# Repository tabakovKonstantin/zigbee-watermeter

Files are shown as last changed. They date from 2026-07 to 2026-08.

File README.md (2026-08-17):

# XIAO ESP32-C6 Zigbee Water Meter

Battery-powered Zigbee water meter firmware for the Seeed Studio XIAO ESP32-C6. It counts Hall-sensor pulses, commits every accepted pulse to NVS, reports standard and custom ZCL attributes to Zigbee2MQTT, supports Zigbee OTA, and uses a hybrid light/deep-sleep policy.

The firmware is C17 on ESP-IDF 5.4.1 with Espressif Zigbee SDK 1.6.x. It is not an Arduino or PlatformIO project.

## Reference Hardware

The table describes the exact tested assembly. Compatible substitutions require their own electrical and power validation.

| Item | Exact reference | Relevant specification | Source |
| :--- | :--- | :--- | :--- |
| MCU board | Seeed Studio XIAO ESP32-C6, ESP32-C6FH4 | 4 MB flash, 512 KB SRAM, native IEEE 802.15.4, 21 x 17.8 mm | [Seeed product guide](https://wiki.seeedstudio.com/xiao_esp32c6_getting_started/), [schematic](https://files.seeedstudio.com/wiki/SeeedStudio-XIAO-ESP32C6/XIAO-ESP32-C6_v1.0_SCH_PDF_24028.pdf) |
| Battery | Marking `YJ781139/2C` | LiPo, 3.7 V nominal, 320 mAh, 1.184 Wh | Cell marking; protection circuit and thresholds are not documented |
| Hall sensor | Texas Instruments `DRV5032FBLPG` | 5 Hz, typically 0.54 uA, omnipolar, push-pull, TO-92/LPG, 1.65-5.5 V | [TI part page](https://www.ti.com/product/DRV5032/part-details/DRV5032FBLPG), [datasheet](https://www.ti.com/lit/ds/symlink/drv5032.pdf) |
| Sensor bypass capacitor | Suntan `008WL2A104KSBB5081R` | 100 nF, 100 V, X7R, +/-10%, through-hole, 5.08 mm pitch | [Comet order code 5774](https://store.comet.bg/en/Catalogue/Product/5774/) |
| Battery divider | `2 x 200 kOhm` resistors | 1:2 divider; exact manufacturer, tolerance, and power rating are unknown | As-built assembly |
| Zigbee antenna | Quectel `YF0023AA` | Adhesive FPC, U.FL, 2.4-2.5 GHz band, 5.0 dBi listed gain, 23 x 12 mm, 100 mm cable | [Comet order code 46832](https://store.comet.bg/en/Catalogue/Product/46832/) |
| Water meter | Maddalena `SJM20.0I0M` as marked | DN20, 130 mm, R100, T50, Q3 4.0 m3/h, `P=10 L` | Unit nameplate; [Maddalena single-jet family](https://www.maddalena.it/en/mecto-sj-plus-sj-evo-water-meter-non-stop-innovation/) |

The LiPo wires are soldered directly to the XIAO `BAT+` and `BAT-` pads. The XIAO onboard charger charges the 3.7 V cell from USB-C. Verify polarity before connecting the battery. Do not connect the cell to `3V3` or `5V`.

## Wiring

```text
LiPo positive  ------------------------------------------ XIAO BAT+
LiPo negative  ------------------------------------------ XIAO BAT- / GND

XIAO BAT+ ---- 200 kOhm ----+---- XIAO A0 / D0 / GPIO0
                             |
                          200 kOhm
                             |
XIAO GND --------------------+

XIAO 3V3 ----------------------------------------------- DRV5032 VCC
XIAO GND ----------------------------------------------- DRV5032 GND
XIAO D1 / GPIO1 <--------------------------------------- DRV5032 OUT

                       100 nF
DRV5032 VCC -------------||----------------------------- DRV5032 GND
                  mount close to sensor

XIAO U.FL ------------------------------------------------ Quectel YF0023AA
```

There is no capacitor on `GPIO0/A0` in the tested battery-divider assembly. The only added capacitor is the 100 nF sensor bypass capacitor between DRV5032 VCC and GND.

The DRV5032 output is push-pull, so GPIO1 has no firmware or external pull-up. A falling edge is one 10 L pulse; a rising edge rearms the input. Holding the output low counts one pulse and then sleeps while waiting for release. An ordinary power-on/reset with the output already low does not count a pulse.

The 200 kOhm/200 kOhm divider draws about 10.5 uA at 4.2 V. GPIO0 uses ESP32-C6 eFuse curve-fitting ADC calibration and 16 averaged samples. Battery percentage is a linear trend indicator from 3300 mV (0%) to 4200 mV (100%), not a precise LiPo state-of-charge model.

## External Antenna

The production assembly uses only the external U.FL antenna. On every full application boot:

- GPIO3 is driven low to enable control of the XIAO RF switch.
- GPIO14 is driven high to select the external U.FL path.
- Both pins are floated immediately before deep sleep to avoid holding the RF switch active.

A missing, damaged, or poorly placed antenna can cause repeated joins or report retries and dominate energy consumption. Test the link with the final enclosure and installation position.

## Enclosure And Print Files

The enclosure models are stored separately from the firmware:

- `enclosure/cad/watermeter_enclosure_box.step` is the STEP exchange model for CAD changes.
- `enclosure/print/watermeter_enclosure_box.stl` is the main enclosure box for 3D printing.
- `enclosure/print/watermeter_enclosure_lid.stl` is the removable enclosure lid.
- `enclosure/print/watermeter_enclosure_sensor_probe.stl` is the probe that holds the Hall sensor in the
  water meter pulse opening.

The repository does not prescribe printer, material, orientation, support, or slicer settings. Verify the fit of all
parts, especially the sensor probe, before final installation.

## Firmware Architecture

| Module | Responsibility |
| :--- | :--- |
| `main/watermeter.c` | Application bootstrap and ESP-IDF platform initialization |
| `main/meter_state.c` | NVS-backed pulse count and scale settings |
| `main/sensor.c` | GPIO ISR, debounce, pulse task, and per-pulse persistence |
| `main/battery.c` | ADC lifecycle and Battery cluster updates |
| `main/battery_math.c` | Pure ADC/divider/percentage calculations |
| `main/meter_math.c` | Pure summation and ZCL integer conversion helpers |
| `main/power_schedule.c` | Pure report and retry scheduling calculations |
| `main/sleep_control.c` | Zigbee sleep, light-sleep sessions, deep-sleep wake/release state |
| `main/xiao_board.c` | XIAO external antenna control |
| `main/zigbee_clusters.c` | Per-cluster builders and endpoint construction |
| `main/zigbee_app.c` | Zigbee lifecycle, commissioning, reporting, and callbacks |
| `main/ota.c` | OTA validation, writing, finalization, and deferred restart |

## Stable Zigbee Contract

Endpoint `1` exposes standard Basic, Identify, Metering, Power Configuration, Poll Control, and OTA client clusters. The externally visible meter contract is:

| Value | Contract |
| :--- | :--- |
| `CurrentSummationDelivered` | Raw persistent pulse count |
| Metering `Multiplier` / `Divisor` | Read-only mirrors of the configured scale |
| Custom `0xFC00` | Scaled summation |
| Custom `0xFC01` | Writable positive scale multiplier |
| Custom `0xFC02` | Writable positive scale divisor |
| Battery voltage / percentage | Standard Power Configuration attributes |
| Default scale | `10 / 1`, so one pulse reports 10 L |

Every accepted pulse is committed to NVS immediately. This intentionally prioritizes water accounting across sudden power loss over flash wear.

## Operations Harness

The dependency-free Python harness is the preferred entry point. It discovers ESP-IDF v5.4.1 and serial ports, reads partition addresses from `partitions.csv`, isolates build profiles, and enforces destructive-operation confirmations.

```bash
python3 tools/watermeter_harness.py doctor
python3 tools/watermeter_harness.py ports
python3 tools/watermeter_harness.py test
python3 tools/watermeter_harness.py build
python3 tools/watermeter_harness.py check-size
```

Run `python3 tools/watermeter_harness.py --help` for all commands. Detailed AI/operator workflows live in:

- `.agents/skills/watermeter-firmware/SKILL.md`
- `.agents/skills/watermeter-hardware-test/SKILL.md`
- `.agents/skills/watermeter-z2m/SKILL.md`

## Manual Build

The equivalent production build is:

```bash
. $HOME/.espressif/tools/activate_idf_v5.4.1.sh
idf.py set-target esp32c6
idf.py build
```

`sdkconfig.defaults` is the production source of truth. Generated `sdkconfig` files are not defaults. The build is valid only when `build/watermeter.bin` is strictly smaller than the `0x1E0000` OTA slot parsed from `partitions.csv`.

Run the pure host tests without an ESP32:

```bash
python3 -m unittest discover -s tests/python -p 'test_*.py'
cmake -S tests -B build-host-tests
cmake --build build-host-tests
ctest --test-dir build-host-tests --output-on-failure
```

## Flash And Logs

Normal flashing builds first and preserves pulse NVS and Zigbee pairing:

```bash
python3 tools/watermeter_harness.py flash --profile production
python3 tools/watermeter_harness.py monitor --profile production
```

The harness auto-selects the port only when exactly one candidate exists. Use `--port` when several boards are connected. XIAO native USB may remain in ROM download mode after flashing; press RESET once without holding BOOT. A disappearing USB port after normal startup is expected when production firmware enters deep sleep.

Do not erase flash to fix a monitor reconnect or ROM download-mode condition.

### Diagnostic Profile

Diagnostic mode has an independent `sdkconfig.diagnostic` and `build-diagnostic`:

```bash
python3 tools/watermeter_harness.py build-diagnostic
python3 tools/watermeter_harness.py flash --profile diagnostic
python3 tools/watermeter_harness.py monitor --profile diagnostic
```

It enables INFO logs and USB Serial/JTAG while preserving NVS and Zigbee storage. It changes awake time and current, so never use it for battery measurements. Restore production firmware after diagnosis.

### Erase Policy

Ordinary flash never erases state. Recovery commands require exact confirmations:

```bash
# Preserves pulse NVS but clears pairing; permit join is required afterward.
python3 tools/watermeter_harness.py erase-zigbee --confirm 'ERASE ZIGBEE'

# Destroys firmware, pulse count, OTA state, and pairing.
python3 tools/watermeter_harness.py erase-all --confirm 'ERASE ALL'
```

The Zigbee partition offset is never copied into documentation or scripts; it is parsed from `partitions.csv` at runtime.

## Sleep Policy

Production uses a hybrid policy. The CPU and Zigbee stack use automatic light sleep while an application session is open, then the device enters deep sleep between sessions.

1. An ordinary power-on/reset does not count GPIO1 already being low.
2. Idle deep sleep waits for GPIO1 or the retained report timer.
3. A falling GPIO wake counts once and commits immediately to NVS.
4. Both mandatory Metering reports must succeed within a 10-second delivery window.
5. If GPIO1 is high, a 30-second activity window reuses the live Zigbee session; every new pulse restarts it.
6. If GPIO1 remains low, the device deep-sleeps waiting for GPIO1 high instead of blocking a task.
7. The release wake rearms GPIO1 low and returns directly to deep sleep without counting or starting Zigbee.
8. A scheduled wake reports the meter and returns to deep sleep without the pulse grace window.

Failed mandatory reports retry after 5, 15, 30, and then 55 minutes. A successful delivery resets the backoff. Factory-new commissioning gets one 2-minute window; later attempts are limited to 10 seconds and use the same backoff. Battery reporting is attempted on first ordinary boot and every 6 hours without blocking meter delivery. OTA temporarily blocks deep sleep and uses a faster parent poll.

### Production Defaults

| Setting | Default |
| :--- | ---: |
| Sleep mode | Hybrid deep/light |
| Active HP CPU | Fixed 160 MHz |
| Sensor debounce | 1 s |
| Normal meter timer | 55 min |
| Battery report timer | 6 h |
| Pulse activity grace | 30 s |
| Mandatory delivery window | 10 s |
| Optional report flush | 500 ms |
| Parent poll during delivery | 1 s |
| Parent poll during OTA | 500 ms |
| Zigbee keep-alive | 55 min |
| End-device aging timeout | 128 min |
| IEEE 802.15.4 TX power | 20 dBm |
| Retry delays | 5/15/30/55 min |

All tunable values are defined in `main/Kconfig.projbuild` and selected in `sdkconfig.defaults`.

## Zigbee2MQTT Converter

The canonical external converter is:

```text
external_converters/zigbeehive-watermeter.mjs
```

The matching device icon is:

```text
external_converters/device_icons/zigbeehive-watermeter.png
```

Zigbee2MQTT 2.11 and newer requires `advanced.enable_external_js: true`. Install the standalone file under the Zigbee2MQTT data directory's `external_converters/` folder. This repository does not own unrelated Tuya or light-sensor converters.

Install the icon under `<zigbee2mqtt-data>/device_icons/` and select it for the device:

```yaml
devices:
  '0xb43a45fffe8a73c4':
    icon: device_icons/zigbeehive-watermeter.png
```

Audit the configured homelab without modifying it:

```bash
python3 tools/watermeter_harness.py z2m-audit
```

Deployment requires the state-bound token printed by a separately reviewed audit plus its typed confirmation. Rollback requires a separate typed confirmation. See `.agents/skills/watermeter-z2m/SKILL.md` before changing the remote host.

## Zigbee OTA

| Header field | Value |
| :--- | :--- |
| Magic | `0x0BEEF11E` |
| Manufacturer code | `0x131B` |
| Image type | `0x0001` |
| File version | Explicit monotonic `OTA_FILE_VERSION` |

Create a local image with an explicit version:

```bash
python3 tools/watermeter_harness.py ota-build --file-version 42
```

GitHub Actions uses `github.run_number`, verifies the binary size, creates the Zigbee `.ota` and `index.json`, and publishes them through GitHub Pages from `main`. Zigbee2MQTT must use the generated index; never offer raw `watermeter.bin` as a Zigbee OTA image.

OTA slots have rollback enabled. A successful boot marks the image valid early in `app_main`. OTA completion schedules a deferred restart instead of restarting inside the Zigbee callback.

## Power Validation

The Hall sensor and divider together account for roughly 11 uA typical before XIAO board losses. A 320 mAh cell discharging in two days therefore indicates substantial additional board current, prolonged awake time, RF retries, charging-path effects, a damaged cell, or another hardware fault; firmware settings alone cannot identify the cause.

Validate in the production profile with USB disconnected:

1. Confirm idle deep-sleep current with GPIO1 high and the coordinator available.
2. Hold the Hall output low and verify one count, no watchdog, and return to deep-sleep current while waiting for release.
3. Turn off the coordinator and verify bounded 10-second attempts followed by configured retry sleeps.
4. Generate pulses less than 30 seconds apart and compare one reused session with repeated cold boots.
5. Test the external antenna in its final placement.
6. Record battery voltage, real pulse activity, outages, and resets over several days.

A multimeter voltage trend can expose severe drain but cannot separate sleep current, radio bursts, regulator loss, and LiPo discharge behavior. Use an in-series current instrument capable of resolving both microamp sleep and radio peaks for a defensible energy budget.

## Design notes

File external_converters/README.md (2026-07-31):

# Zigbee2MQTT External Converter

`zigbeehive-watermeter.mjs` is the canonical and only WaterMeter converter maintained by this repository. It is a standalone ES module for Zigbee2MQTT 2.x.

Install it as:

```text
<zigbee2mqtt-data>/external_converters/zigbeehive-watermeter.mjs
```

Install the matching device icon as:

```text
<zigbee2mqtt-data>/device_icons/zigbeehive-watermeter.png
```

Then reference it from the device entry in `configuration.yaml`:

```yaml
devices:
  '0xb43a45fffe8a73c4':
    icon: device_icons/zigbeehive-watermeter.png
```

Zigbee2MQTT 2.11 and newer requires:

```yaml
advanced:
  enable_external_js: true
```

Audit the configured homelab before any deployment:

```bash
python3 tools/watermeter_harness.py z2m-audit
```

The audit is read-only. Deployment requires a clean, reviewed audit, its state-bound approval token, and the exact `DEPLOY Z2M` confirmation. See `.agents/skills/watermeter-z2m/SKILL.md` for legacy-bundle migration, complete-set backup, health checks, and rollback.

The converter exposes:

```text
pulse_count        read-only raw CurrentSummationDelivered pulses
scaled_summation   read-only pulse_count * scale_multiplier / scale_divisor
water_consumed     read-only liters for Home Assistant Energy
scale_multiplier   writable positive integer stored in device NVS
scale_divisor      writable positive integer stored in device NVS
multiplier         read-only standard Metering mirror
divisor            read-only standard Metering mirror
battery
voltage
```

The default scale is `10 / 1`, so one pulse is 10 L.

Unrelated Tuya, thermostat, or light-sensor converters belong to the Zigbee2MQTT installation that uses them. Do not add them to this firmware repository or combine them with the canonical WaterMeter converter.

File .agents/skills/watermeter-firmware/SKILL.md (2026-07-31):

---
name: watermeter-firmware
description: Build, test, flash, monitor, diagnose, and prepare USB or Zigbee OTA updates for the zigbee-watermeter ESP-IDF firmware. Use for firmware operations, serial-port discovery, production or diagnostic profiles, partition erasure, OTA image creation, binary-size checks, or ESP32-C6 troubleshooting in this repository.
---

# Watermeter Firmware

Use `tools/watermeter_harness.py` from the repository root. Treat `sdkconfig.defaults`,
`sdkconfig.diagnostic.defaults`, and `partitions.csv` as the configuration sources of truth.

## Preserve Invariants

- Use ESP-IDF v5.4.1 and target `esp32c6`.
- Keep every pulse committed to NVS immediately.
- Preserve Zigbee endpoint 1, Metering and Battery attributes, custom attributes `0xFC00`-`0xFC02`, and report formats.
- Preserve OTA magic `0x0BEEF11E`, manufacturer `0x131B`, image type `0x0001`, and dual-slot compatibility.
- Require `watermeter.bin` to be strictly smaller than the OTA slot parsed from `partitions.csv`.
- Never hardcode a serial port or partition offset. Discover the port and parse the table.
- Never erase NVS or Zigbee storage as part of an ordinary build, flash, diagnostic, or update.

## Choose The Operation

Run the environment check first on a new machine or after an ESP-IDF change:

```bash
python3 tools/watermeter_harness.py doctor
python3 tools/watermeter_harness.py ports
```

Run local tests and a production build after firmware or tooling changes:

```bash
python3 tools/watermeter_harness.py test
python3 tools/watermeter_harness.py build
python3 tools/watermeter_harness.py check-size
```

Use `--clean` only when configuration or generated build state is suspect. It removes only the selected build directory.

## Flash Safely

Build and flash production firmware without erasing state:

```bash
python3 tools/watermeter_harness.py flash --profile production
```

Pass `--port` only when more than one candidate is connected. After native USB flashing, the XIAO may remain in ROM download mode. Press RESET once without holding BOOT. Do not erase the board to fix this condition.

Monitor with the ELF matching the flashed profile:

```bash
python3 tools/watermeter_harness.py monitor --profile production
```

When an agent starts the monitor, allocate a TTY. Expect the USB port to disappear during deep sleep.

## Use Diagnostic Mode

Keep diagnostic output isolated from production artifacts:

```bash
python3 tools/watermeter_harness.py build-diagnostic
python3 tools/watermeter_harness.py flash --profile diagnostic
python3 tools/watermeter_harness.py monitor --profile diagnostic
```

Diagnostic mode enables INFO logging and USB Serial/JTAG. It preserves NVS and Zigbee pairing but changes awake time and board current. Never use it for battery-life measurements. Restore production firmware after diagnosis with `flash --profile production`.

## Erase Only With Explicit Approval

Use `erase-zigbee` only to recover corrupted pairing state. It reads the current `zb_storage` offset and size from `partitions.csv`, preserves pulse NVS, and requires re-pairing:

```bash
python3 tools/watermeter_harness.py erase-zigbee --confirm 'ERASE ZIGBEE'
```

Use `erase-all` only after the user explicitly accepts losing firmware, pulse count, OTA state, and Zigbee pairing:

```bash
python3 tools/watermeter_harness.py erase-all --confirm 'ERASE ALL'
```

Never infer either confirmation from a general request to flash, clean, repair, or retry.

## Prepare OTA

Require a user-selected monotonically increasing file version:

```bash
python3 tools/watermeter_harness.py ota-build --file-version 42
```

The command builds production firmware, checks its slot size, and writes the `.ota` image and index under `build/ota`. It does not push Git or publish a release. CI uses `github.run_number` and publishes from `main` through GitHub Pages.

## Finish A Change

Run Python/C tests, the production build, and the diagnostic build. Report both binary sizes and any test that could not run. Do not claim a hardware, Zigbee delivery, deep-sleep current, or OTA result from compilation alone.

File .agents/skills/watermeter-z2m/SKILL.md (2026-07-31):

---
name: watermeter-z2m
description: Audit, migrate, deploy, verify, and roll back the ZigbeeHive watermeter external converter on the homelab Zigbee2MQTT installation. Use for converter drift, Zigbee2MQTT support, remote configuration, external converter migration, service restart, health checks, or rollback involving homelab.lan.
---

# Watermeter Zigbee2MQTT

Use the canonical local converter at `external_converters/zigbeehive-watermeter.mjs`. The default remote installation is:

```text
SSH host:     homelab.lan
Data:         /mnt/projects/smart_home/zigbee2mqtt-data
Compose file: /mnt/projects/smart_home/compose.yml
Service:      zigbee2mqtt
Container:    zigbee2mqtt
```

The canonical local device icon is `external_converters/device_icons/zigbeehive-watermeter.png`. Install it as `device_icons/zigbeehive-watermeter.png` under the Zigbee2MQTT data directory and reference that relative path from the device entry in `configuration.yaml`.

Use SSH configuration or an SSH agent. Never place credentials or private keys in the repository.

## Audit First

Always begin with the read-only operation:

```bash
python3 tools/watermeter_harness.py z2m-audit
```

The audit checks the compose service, `advanced.enable_external_js`, converter syntax inside the running Zigbee2MQTT container, the canonical file diff, and duplicate legacy WaterMeter definitions. It may display a deployment diff but must not write or restart anything.

## Handle The One-Time Legacy Split

The existing homelab may contain one CommonJS aggregate with unrelated Tuya/TS0222 converters and a copied WaterMeter definition. This repository must not own those unrelated definitions.

If audit reports a legacy conflict:

1. Read and preserve the complete remote aggregate.
2. Prepare a timestamped backup under `/mnt/projects/smart_home/zigbee2mqtt-data/.watermeter-backups`.
3. Split only the unrelated definitions into a remote-only converter file. Preserve their imports, fingerprints, exposes, datapoints, and exports exactly.
4. Remove the WaterMeter definition from the legacy file and stage the canonical `.mjs` as a separate file.
5. Move the old aggregate outside the auto-loaded `.js`/`.mjs` paths or give the backup a non-JavaScript suffix.
6. Validate syntax in the Zigbee2MQTT container and show the exact remote diff.
7. Ask for explicit approval before writing files or restarting the service.

Do not automate this split with substring deletion when the remote file shape is uncertain. Never alter unrelated converter behavior to make the migration cleaner.

## Deploy The Canonical Converter

Deploy only after audit is clean and the user explicitly approves the shown diff and restart. Pass the token printed by that separately reviewed audit so deployment is bound to the same local and remote converter state:

```bash
python3 tools/watermeter_harness.py z2m-deploy \
    --approved-audit <token-from-z2m-audit> \
    --confirm 'DEPLOY Z2M'
```

The command reruns the audit and refuses a stale or missing token. It then backs up the current WaterMeter target, uploads to a temporary `.mjs`, checks syntax inside the container, atomically replaces the target, restarts only `zigbee2mqtt`, and prints status and recent logs. It refuses deployment while another file still defines WaterMeter.

Do not change `configuration.yaml`, other services, devices, or unrelated converters as a side effect. If `advanced.enable_external_js` is disabled, prepare and show that configuration change separately and request approval.

## Verify

After restart, require all of the following:

- the `zigbee2mqtt` service is running;
- no external-converter syntax/load error appears in recent logs;
- model `ZigbeeHive-WaterMeter` is supported;
- existing unrelated devices remain supported;
- `pulse_count`, `scaled_summation`, `water_consumed`, battery, and voltage remain available;
- writable scale values remain positive and preserve their previous values.
- the configured device icon path exists and remains scoped to the WaterMeter device.

Do not generate test pulses remotely. Use the hardware-test skill when an end-to-end pulse is required.

## Roll Back

Never roll back silently. Show the retained backup timestamp and request a separate confirmation:

```bash
python3 tools/watermeter_harness.py z2m-rollback \
    --backup 20260731T153000Z \
    --confirm 'ROLLBACK Z2M'
```

The generic rollback command restores only a standalone canonical-converter deployment. It must refuse a one-time legacy-split backup marked by `MIGRATION.txt`; restoring that backup requires the complete configuration and converter set described in the marker and a separately reviewed command.

Restart only Zigbee2MQTT and repeat the health checks. Never delete old backups automatically.

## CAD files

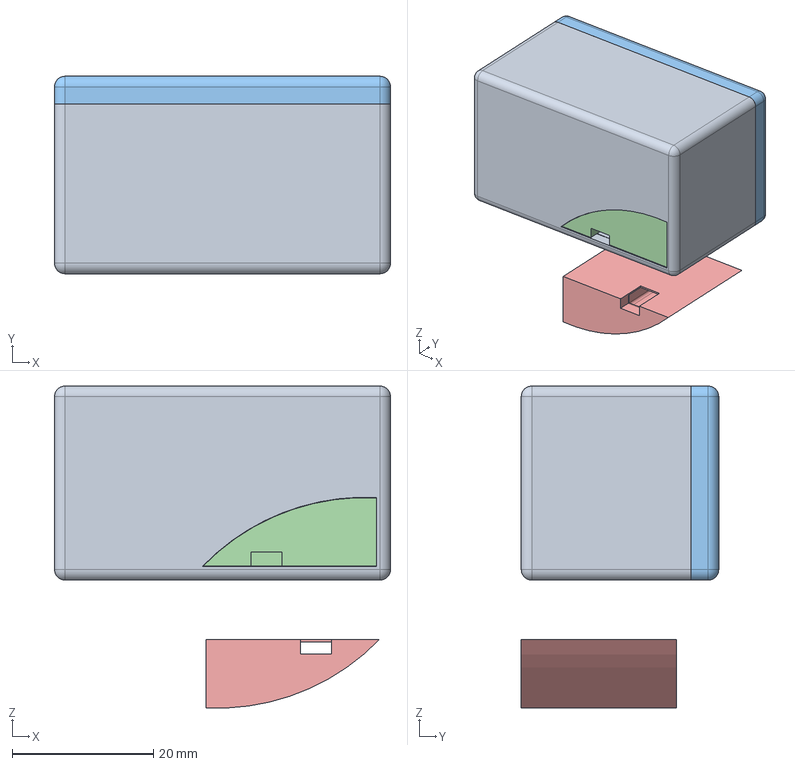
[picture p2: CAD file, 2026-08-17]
enclosure/cad/watermeter_enclosure_box.step
47.6 x 28.0 x 45.6 mm

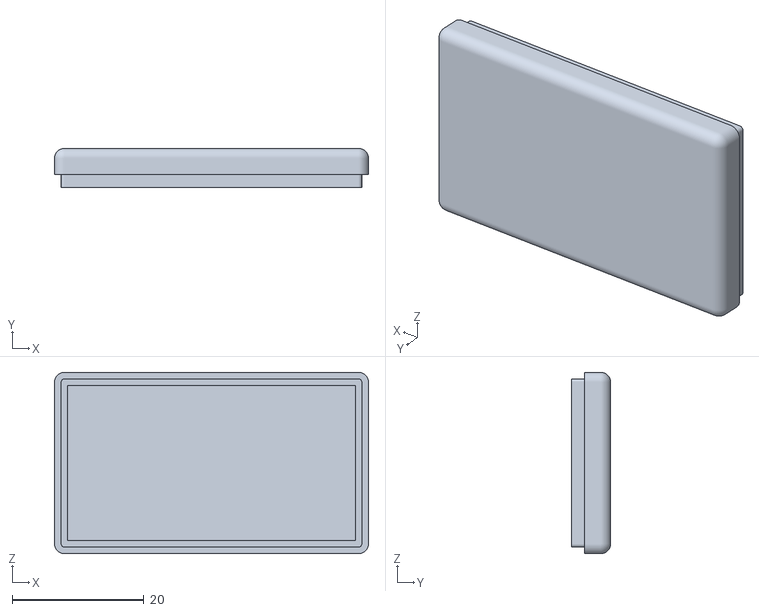
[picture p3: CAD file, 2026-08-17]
enclosure/print/watermeter_enclosure_lid.stl
47.6 x 5.95 x 27.5

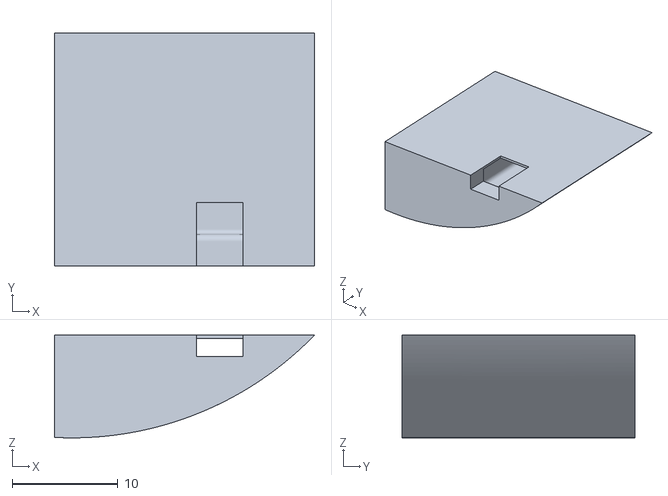
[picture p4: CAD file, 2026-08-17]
enclosure/print/watermeter_enclosure_sensor_probe.stl
24.5 x 22.0 x 9.70

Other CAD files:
enclosure/print/watermeter_enclosure_box.stl

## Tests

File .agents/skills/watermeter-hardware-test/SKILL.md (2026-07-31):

---
name: watermeter-hardware-test
description: Guide a human through safe functional and battery testing of the XIAO ESP32-C6 Zigbee water meter. Use when validating Hall pulses, stuck-low handling, phantom-pulse prevention, watchdog behavior, deep-sleep wake/release behavior, Zigbee2MQTT delivery, production restoration, or battery drain on the physical device.
---

# Watermeter Hardware Test

Run hardware validation as a human-in-the-loop procedure. Ask for one physical action at a time and wait for the result. Never pretend that a GPIO, magnet, reset button, USB cable, Zigbee coordinator, or meter was manipulated automatically.

## Protect Meter Data

- Read the current `pulse_count` from logs or Zigbee2MQTT before generating a test pulse.
- Warn that every accepted magnet pulse permanently adds one count, equal to 10 L with the production scale.
- Require explicit approval before test pulses.
- Never erase, decrement, rewrite, or compensate the NVS counter after a test.
- Record the expected and observed counter delta.

## Phase 1: Functional Diagnostic Test

Use USB power and the diagnostic profile. This phase checks behavior, not energy consumption.

1. Run `python3 tools/watermeter_harness.py doctor` and `ports`.
2. Flash with `python3 tools/watermeter_harness.py flash --profile diagnostic`. Do not erase flash.
3. Ask the user to press RESET once without BOOT if the board remains in ROM download mode.
4. Start `monitor --profile diagnostic` with a TTY and capture the baseline pulse count, boot cause, network state, and absence of NVS errors.
5. Confirm in Zigbee2MQTT that the device is recognized as `ZigbeeHive-WaterMeter` before pulse tests.

### Single Pulse

1. Confirm the Hall output is released/high.
2. Ask the user to apply the magnet once and then remove it.
3. Verify exactly one `Pulse counted` entry and a counter delta of one.
4. Reject repeated counts, queue floods, watchdog messages, or NVS errors.
5. Allow delivery on the current or a later scheduled wake; do not require an unnecessary retry loop.

### Stuck-Low And Release

1. Confirm the user accepts one additional permanent test pulse.
2. Ask the user to apply and hold the magnet for at least 15 seconds.
3. Verify one pulse only, no task-watchdog trigger, and no repeated count while the output remains low.
4. Expect deep sleep to arm a high-level wake while waiting for release; the USB port may disappear.
5. Ask the user to remove the magnet.
6. Verify the release wake rearms the low-level wake without incrementing the counter or starting a full Zigbee session.
7. Apply one later normal pulse to prove the input was rearmed; expect one additional count only.

### Reset And Phantom Pulse

1. With the Hall output released/high, reset and verify no count.
2. Hold the magnet before an ordinary RESET and keep it held through boot.
3. Verify an ordinary power-on/reset with GPIO1 already low does not count a pulse.
4. Remove the magnet and verify release does not count.
5. Stop immediately on any phantom increment or watchdog output and retain the complete log.

### Zigbee2MQTT Delivery

Verify that `pulse_count`, `scaled_summation`, and `water_consumed` converge to the expected values in Zigbee2MQTT. A mandatory delivery attempt may stop after 10 seconds and retry on a later wake. Treat eventual correct delivery without data loss as success; do not keep the device awake merely to force an immediate UI update.

## Restore Production

After functional testing:

```bash
python3 tools/watermeter_harness.py flash --profile production
```

Press RESET once without BOOT if needed. Confirm production boot, then disconnect USB. Do not leave diagnostic firmware installed for power testing.

## Phase 2: Battery Test

- Use the production profile and the final external U.FL antenna and enclosure placement.
- Power only from the 3.7 V LiPo through `BAT+`/`BAT-`; disconnect USB.
- Keep the Zigbee coordinator and parent in their normal production locations.
- Record battery voltage, timestamps, real water activity, coordinator outages, and resets over several days.
- A multimeter voltage trend can expose severe drain but cannot separate deep-sleep current, regulator loss, radio retries, or LiPo discharge-curve effects.
- For a defensible energy budget, measure current in series with the battery using equipment that resolves sleep current and radio bursts.

Do not promise a battery lifetime from voltage snapshots alone. Report observed conditions and uncertainty.

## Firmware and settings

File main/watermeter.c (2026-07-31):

#include "esp_app_desc.h"
#include "esp_log.h"
#include "esp_sleep.h"
#include "esp_zigbee_core.h"
#include "nvs_flash.h"

#include "battery.h"
#include "meter_state.h"
#include "ota.h"
#include "sensor.h"
#include "sleep_control.h"
#include "xiao_board.h"
#include "zigbee_app.h"

#define SENSOR_PIN CONFIG_WATERMETER_SENSOR_GPIO

static const char *TAG = "WATERMETER";

void app_main(void)
{
    esp_zb_platform_config_t config = {
        .radio_config = { .radio_mode = ZB_RADIO_MODE_NATIVE },
        .host_config = { .host_connection_mode = ZB_HOST_CONNECTION_MODE_NONE },
    };

    sleep_control_handle_early_wakeup();

    ESP_ERROR_CHECK(nvs_flash_init());
    ESP_LOGI(TAG, "app_main: nvs ok");
    esp_sleep_wakeup_cause_t boot_wakeup_cause = esp_sleep_get_wakeup_cause();
    ESP_LOGI(TAG, "app_main: boot wake cause=%s (%d)",
             sleep_control_wakeup_cause_name(boot_wakeup_cause), boot_wakeup_cause);

    ota_set_activity_callback(zigbee_app_set_ota_active);
    ESP_ERROR_CHECK(ota_mark_running_app_valid());
    ESP_LOGI(TAG, "app_main: firmware=%s ota_file_version=%d", esp_app_get_description()->version,
             WATERMETER_OTA_FILE_VERSION);

    ESP_ERROR_CHECK(meter_state_load());
    ESP_LOGI(TAG, "app_main: meter state ok");

    esp_err_t battery_err = battery_init();
    if (battery_err == ESP_OK) {
        ESP_LOGI(TAG, "app_main: calibrated battery adc ok on ADC1 channel 0");
    } else {
        ESP_LOGW(TAG, "app_main: battery adc unavailable: %s", esp_err_to_name(battery_err));
    }

    ESP_ERROR_CHECK(sleep_control_init_power_management());
    ESP_LOGI(TAG, "app_main: power management fixed at %d MHz", CONFIG_WATERMETER_PM_MAX_FREQ_MHZ);

    ESP_ERROR_CHECK(xiao_board_enable_external_antenna());
    ESP_ERROR_CHECK(esp_zb_platform_config(&config));
    ESP_LOGI(TAG, "app_main: zigbee platform config ok");

    const sensor_callbacks_t sensor_callbacks = {
        .is_zigbee_joined = zigbee_app_is_joined,
        .report_pulse = zigbee_app_report_sensor_pulse,
    };
    ESP_ERROR_CHECK(sensor_start(&sensor_callbacks));
    ESP_LOGI(TAG, "app_main: sensor task created");

    ESP_ERROR_CHECK(zigbee_app_start());
    ESP_LOGI(TAG, "app_main: zigbee task created");

    ESP_LOGI(TAG, "Sleep mode=%s sensor GPIO=%d", sleep_control_mode_name(), SENSOR_PIN);
}

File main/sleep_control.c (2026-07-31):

#include "sleep_control.h"

#include <inttypes.h>

#include "driver/gpio.h"
#include "esp_attr.h"
#include "esp_log.h"
#include "esp_pm.h"
#include "esp_zigbee_cluster.h"
#include "esp_zigbee_core.h"
#include "platform/esp_zigbee_platform.h"
#include "soc/esp32c6/rtc.h"

#include "ota.h"
#include "xiao_board.h"

#define SENSOR_PIN ((gpio_num_t)CONFIG_WATERMETER_SENSOR_GPIO)
#define ZIGBEE_SLEEP_THRESHOLD_MS 1000
#define ZIGBEE_AWAKE_AFTER_PULSE_MS 3000
#define SENSOR_WAKE_STATE_MAGIC 0x574D5357U
#define MIN_DEEP_SLEEP_MS 100

#if CONFIG_WATERMETER_SLEEP_MODE_DEEP && !GPIO_IS_DEEP_SLEEP_WAKEUP_VALID_GPIO(CONFIG_WATERMETER_SENSOR_GPIO)
#error "WATERMETER_SENSOR_GPIO must be a valid deep sleep wake GPIO in deep sleep mode"
#endif

static const char *TAG = "SLEEP_CONTROL";

static QueueHandle_t s_sensor_queue;
static bool s_joined;

#if CONFIG_WATERMETER_SLEEP_MODE_DEEP
RTC_DATA_ATTR static uint32_t s_sensor_wake_state_magic;
RTC_DATA_ATTR static uint8_t s_sensor_wake_level;
RTC_DATA_ATTR static uint64_t s_timer_deadline_us;

static uint32_t s_requested_wake_after_ms = CONFIG_WATERMETER_REPORT_INTERVAL_MS;

static void deep_sleep_enter_cb(uint8_t arg);
static void enter_deep_sleep(bool preserve_timer_deadline);
#endif

const char *sleep_control_wakeup_cause_name(esp_sleep_wakeup_cause_t cause)
{
    switch (cause) {
    case ESP_SLEEP_WAKEUP_UNDEFINED:
        return "undefined";
    case ESP_SLEEP_WAKEUP_TIMER:
        return "timer";
    case ESP_SLEEP_WAKEUP_GPIO:
        return "gpio";
    default:
        return "other";
    }
}

const char *sleep_control_mode_name(void)
{
#if CONFIG_WATERMETER_SLEEP_MODE_LIGHT
    return "light";
#elif CONFIG_WATERMETER_SLEEP_MODE_DEEP
    return "deep";
#else
    return "off";
#endif
}

bool sleep_control_handle_early_wakeup(void)
{
#if CONFIG_WATERMETER_SLEEP_MODE_DEEP
    if (esp_sleep_get_wakeup_cause() != ESP_SLEEP_WAKEUP_GPIO ||
        s_sensor_wake_state_magic != SENSOR_WAKE_STATE_MAGIC ||
        s_sensor_wake_level == 0) {
        return false;
    }

    s_sensor_wake_state_magic = 0;
    gpio_config_t sensor_config = {
        .pin_bit_mask = 1ULL << SENSOR_PIN,
        .mode = GPIO_MODE_INPUT,
        .pull_up_en = GPIO_PULLUP_DISABLE,
        .pull_down_en = GPIO_PULLDOWN_DISABLE,
        .intr_type = GPIO_INTR_DISABLE,
    };
    ESP_ERROR_CHECK(gpio_config(&sensor_config));
    ESP_LOGI(TAG, "Hall release wake; rearming without starting the application");
    enter_deep_sleep(true);
    return true;
#else
    return false;
#endif
}

#if CONFIG_WATERMETER_SLEEP_MODE_DEEP
static bool sleep_allowed_now(void)
{
    return !ota_is_in_progress();
}
#endif

static void drain_sensor_queue(void)
{
    uint32_t ignored_gpio = 0;
    uint32_t drained = 0;

    while (s_sensor_queue && xQueueReceive(s_sensor_queue, &ignored_gpio, 0) == pdTRUE) {
        drained++;
    }
    if (drained > 0) {
        ESP_LOGI(TAG, "Drained %" PRIu32 " queued duplicate sensor events", drained);
    }
}

#if CONFIG_WATERMETER_SLEEP_MODE_LIGHT
static void enable_zigbee_sleep_cb(uint8_t arg)
{
    (void)arg;
    if (ota_is_in_progress()) {
        ESP_LOGI(TAG, "Keep Zigbee sleep disabled during OTA");
        return;
    }
    ESP_LOGI(TAG, "Re-enable Zigbee sleep after pulse report");
    esp_zb_sleep_enable(true);
}
#endif

void sleep_control_set_sensor_queue(QueueHandle_t queue)
{
    s_sensor_queue = queue;
}

void sleep_control_set_joined(bool joined)
{
    s_joined = joined;
}

void sleep_control_set_ota_active(bool active)
{
    esp_zb_set_default_long_poll_interval(active ? CONFIG_WATERMETER_OTA_POLL_INTERVAL_MS
                                                 : CONFIG_WATERMETER_ZIGBEE_KEEP_ALIVE_MS);
#if CONFIG_WATERMETER_SLEEP_MODE_LIGHT
    esp_zb_sleep_enable(!active);
#elif CONFIG_WATERMETER_SLEEP_MODE_DEEP
    if (active) {
        esp_zb_scheduler_alarm_cancel((esp_zb_callback_t)deep_sleep_enter_cb, 0);
    }
#else
    (void)active;
#endif
}

void sleep_control_configure_zigbee(void)
{
    esp_zb_set_default_long_poll_interval(CONFIG_WATERMETER_PARENT_POLL_INTERVAL_MS);
#if CONFIG_WATERMETER_SLEEP_MODE_LIGHT
    esp_zb_set_rx_on_when_idle(false);
    ESP_ERROR_CHECK(esp_zb_sleep_set_threshold(ZIGBEE_SLEEP_THRESHOLD_MS));
    esp_zb_sleep_enable(true);
    ESP_LOGI(TAG, "Enable Zigbee-managed light sleep, rx_on_when_idle=%s",
             esp_zb_get_rx_on_when_idle() ? "true" : "false");
#elif CONFIG_WATERMETER_SLEEP_MODE_DEEP
    esp_zb_set_rx_on_when_idle(false);
    ESP_ERROR_CHECK(esp_zb_sleep_set_threshold(ZIGBEE_SLEEP_THRESHOLD_MS));
    esp_zb_sleep_enable(true);
    ESP_LOGI(TAG, "Enable Zigbee sleepy end-device mode for deep sleep, rx_on_when_idle=%s",
             esp_zb_get_rx_on_when_idle() ? "true" : "false");
#else
    esp_zb_set_rx_on_when_idle(true);
    esp_zb_sleep_enable(false);
    ESP_LOGI(TAG, "Zigbee stack sleep disabled for sleep mode=%s, rx_on_when_idle=%s",
             sleep_control_mode_name(), esp_zb_get_rx_on_when_idle() ? "true" : "false");
#endif
}

esp_err_t sleep_control_init_power_management(void)
{
#if CONFIG_WATERMETER_SLEEP_MODE_LIGHT || CONFIG_WATERMETER_SLEEP_MODE_DEEP
    const esp_pm_config_t pm_config = {
        .max_freq_mhz = CONFIG_WATERMETER_PM_MAX_FREQ_MHZ,
        .min_freq_mhz = CONFIG_WATERMETER_PM_MAX_FREQ_MHZ,
        .light_sleep_enable = true,
    };
    return esp_pm_configure(&pm_config);
#else
    return ESP_OK;
#endif
}

void sleep_control_keep_awake_for_pulse_report(void)
{
    esp_zb_lock_acquire(portMAX_DELAY);
#if CONFIG_WATERMETER_SLEEP_MODE_LIGHT
    ESP_LOGI(TAG, "Keep Zigbee awake for %d ms after pulse report", ZIGBEE_AWAKE_AFTER_PULSE_MS);
    esp_zb_sleep_enable(false);
    esp_zb_scheduler_alarm_cancel((esp_zb_callback_t)enable_zigbee_sleep_cb, 0);
    esp_zb_scheduler_alarm((esp_zb_callback_t)enable_zigbee_sleep_cb, 0, ZIGBEE_AWAKE_AFTER_PULSE_MS);
#elif CONFIG_WATERMETER_SLEEP_MODE_DEEP
    ESP_LOGI(TAG, "Cancel pending deep sleep for pulse report");
    esp_zb_scheduler_alarm_cancel((esp_zb_callback_t)deep_sleep_enter_cb, 0);
#endif
    esp_zb_lock_release();
}

void sleep_control_enqueue_sensor_wakeup(void)
{
#if CONFIG_WATERMETER_SLEEP_MODE_LIGHT
    if (!s_sensor_queue) {
        return;
    }

    esp_sleep_wakeup_cause_t cause = esp_sleep_get_wakeup_cause();
    int level = gpio_get_level(SENSOR_PIN);
    ESP_LOGI(TAG, "Light-sleep wakeup check: cause=%s (%d) GPIO%d level=%d",
             sleep_control_wakeup_cause_name(cause), cause, SENSOR_PIN, level);
    if (cause == ESP_SLEEP_WAKEUP_GPIO && level == 0) {
        uint32_t gpio_num = SENSOR_PIN;
        if (xQueueSend(s_sensor_queue, &gpio_num, 0) != pdTRUE) {
            ESP_LOGW(TAG, "Sensor queue full after light-sleep GPIO wakeup");
        }
    }
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

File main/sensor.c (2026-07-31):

#include "sensor.h"

#include <inttypes.h>
#include <stdint.h>

#include "driver/gpio.h"
#include "esp_log.h"
#include "esp_sleep.h"
#include "esp_timer.h"
#include "freertos/FreeRTOS.h"
#include "freertos/queue.h"
#include "freertos/task.h"

#include "meter_state.h"
#include "sleep_control.h"

#define SENSOR_PIN ((gpio_num_t)CONFIG_WATERMETER_SENSOR_GPIO)
#define SENSOR_QUEUE_LEN 8
#define SENSOR_DEBOUNCE_US ((int64_t)CONFIG_WATERMETER_SENSOR_DEBOUNCE_MS * 1000LL)
#define ZIGBEE_WAKE_BEFORE_REPORT_MS 200

static const char *TAG = "SENSOR";

static QueueHandle_t s_sensor_queue;
static sensor_callbacks_t s_callbacks;

static void IRAM_ATTR sensor_isr_handler(void *arg)
{
    uint32_t gpio_num = (uint32_t)arg;
    BaseType_t higher_priority_task_woken = pdFALSE;
    xQueueSendFromISR(s_sensor_queue, &gpio_num, &higher_priority_task_woken);
    if (higher_priority_task_woken) {
        portYIELD_FROM_ISR();
    }
}

static void sensor_task(void *pvParameters)
{
    (void)pvParameters;

    gpio_config_t io_conf = {
        .pin_bit_mask = (1ULL << SENSOR_PIN),
        .mode = GPIO_MODE_INPUT,
        .pull_up_en = GPIO_PULLUP_DISABLE,
        .pull_down_en = GPIO_PULLDOWN_DISABLE,
        .intr_type = GPIO_INTR_NEGEDGE,
    };
    ESP_ERROR_CHECK(gpio_config(&io_conf));
#if CONFIG_WATERMETER_SLEEP_MODE_LIGHT || CONFIG_WATERMETER_SLEEP_MODE_DEEP
    ESP_ERROR_CHECK(gpio_wakeup_enable(SENSOR_PIN, GPIO_INTR_LOW_LEVEL));
    ESP_ERROR_CHECK(esp_sleep_enable_gpio_wakeup());
    /* gpio_wakeup_enable() selects a level interrupt; keep the active ISR edge-triggered. */
    ESP_ERROR_CHECK(gpio_set_intr_type(SENSOR_PIN, GPIO_INTR_NEGEDGE));
#endif
    ESP_ERROR_CHECK(gpio_install_isr_service(0));
    ESP_ERROR_CHECK(gpio_isr_handler_add(SENSOR_PIN, sensor_isr_handler, (void *)SENSOR_PIN));
#if CONFIG_WATERMETER_SLEEP_MODE_DEEP
    sleep_control_enqueue_sensor_wakeup();
#endif

    ESP_LOGI(TAG, "Sensor interrupt started on GPIO%d", SENSOR_PIN);

    uint32_t gpio_num = 0;
    int64_t last_pulse_us = 0;
    while (1) {
        if (xQueueReceive(s_sensor_queue, &gpio_num, portMAX_DELAY) != pdTRUE) {
            continue;
        }

        int64_t now_us = esp_timer_get_time();
        if (last_pulse_us != 0 && (now_us - last_pulse_us) < SENSOR_DEBOUNCE_US) {
            ESP_LOGD(TAG, "Ignore GPIO%" PRIu32 " pulse inside debounce window", gpio_num);
            continue;
        }
        last_pulse_us = now_us;

        uint64_t pulses = meter_state_increment_pulse();
        esp_err_t err = meter_state_save();
        if (err != ESP_OK) {
            ESP_LOGE(TAG, "Failed to save pulse count: %s", esp_err_to_name(err));
        }

        ESP_LOGI(TAG, "Pulse counted on GPIO%" PRIu32 ", total=%" PRIu64, gpio_num, pulses);
        if (s_callbacks.is_zigbee_joined()) {
            sleep_control_keep_awake_for_pulse_report();
            vTaskDelay(pdMS_TO_TICKS(ZIGBEE_WAKE_BEFORE_REPORT_MS));
        }
        s_callbacks.report_pulse();
        sleep_control_finish_sensor_pulse();
        last_pulse_us = esp_timer_get_time();
    }
}

esp_err_t sensor_start(const sensor_callbacks_t *callbacks)
{
    if (!callbacks || !callbacks->is_zigbee_joined || !callbacks->report_pulse) {
        return ESP_ERR_INVALID_ARG;
    }
    s_callbacks = *callbacks;

    s_sensor_queue = xQueueCreate(SENSOR_QUEUE_LEN, sizeof(uint32_t));
    if (!s_sensor_queue) {
        return ESP_ERR_NO_MEM;
    }
    sleep_control_set_sensor_queue(s_sensor_queue);

    return xTaskCreate(sensor_task, "sensor", 4096, NULL, 6, NULL) == pdPASS ? ESP_OK : ESP_FAIL;
}

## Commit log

2025-11-27 First version of watermeter
    [partitions.csv]
2025-11-27 Move to flow instead of meter
2026-06-22 Retry Zigbee steering after rejoin failure
    [watermeter.c]
2026-06-26 Tune water meter sleep and ADC reporting
2026-07-02 Add Zigbee OTA update support
    [partitions.csv]
2026-07-06 Calibrate battery reporting
2026-07-29 Preserve battery calibration baseline
2026-07-29 Bound sensor release wait
2026-07-29 Remove unused LED strip dependency
2026-07-29 Extract battery monitoring module
2026-07-30 Extract pulse sensor task
2026-07-30 Configure XIAO low-power hardware policy
2026-07-30 Handle persistent Hall sensor levels safely
2026-07-30 Rearm Hall wake without starting Zigbee
2026-07-30 Calibrate battery ADC from eFuse
2026-07-30 Document hybrid sleep and XIAO wiring
2026-07-30 Preserve Hall wake in light sleep
2026-07-31 Stabilize Zigbee and Hall wake handling
    [sensor.c, sleep_control.c, watermeter.c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]
2026-08-17 Add watermeter enclosure models
    [watermeter_enclosure_box.step, watermeter_enclosure_box.stl, watermeter_enclosure_lid.stl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]
2026-08-17 Document and organize enclosure models
    [watermeter_enclosure_box.step, watermeter_enclosure_box.stl, watermeter_enclosure_lid.stl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]
